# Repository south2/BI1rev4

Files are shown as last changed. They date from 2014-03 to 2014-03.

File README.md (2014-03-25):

BI1rev4
=======

BI1 revision 4 (myf14 evaluated, myf17 is work in progress)

The “body interactor”(BI) is a printed circuit board (PCB) with a vibrator motor, an accelerometer, a LiPo battery and battery charger and wireless radio frequency (RF) communication. The board can be programmed with the Arduino software.

The BI is designed for building a wearable autonomous device: With the accelerometer, movement data can be recorded and send to other BI by wireless RF communication. Gestures can be recognised and used for controlling the vibrator motor as well as other devices and applications using wireless communication (e.g. other BIs, computer games).

Different vibration pattern can be used to give the wearer information or feedback. Other use cases for vibration are massage application or moving objects (e.g. “vibrobot”).

The development board is particular suitable for people who are interested in application development using this kind of hardware arrangement and to construct an individual printed encasement for the board. Board, 3D printed encasement and Arduino program together are the individual final product. In addition the wireless communication function offers applications comprising multiple BI in different cases and with different tasks. In contrast changes, adaption or extensions (shields) of the board are rather complex.

www.bodyinteraction.com/about

Encasements

http://www.thingiverse.com/thing:109167

http://www.thingiverse.com/thing:259780

Data

- Atmel Attiny84 (8kbyte)
- LiPo charger (via USB)
- LiPo battery
- vibration motor (PWM controlled)
- BMA020 accelerometer
- two additional I/O ports  
- ISP interface (2×3 pole header) for programming
- RFM12B (915 or 868 Mhz)
- approx.  22×35 mm
- open source hardware

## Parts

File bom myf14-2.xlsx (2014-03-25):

 | BOM | 2014-03-12
 | Exported | from | myf14.brd
Quantity | Part | Value | Package (size in mm) | Orientation | Price (€) | Description (Package size in inch) | Ordered from | Order-ID | Manufacturer Part No | Remarks
2 | C4 | 1micro | 0603-CAP | R180 | 0.04 | Multilayer Ceramic Capacitors MLCC - SMD/SMT CAP, MLCC, 0201, 50V C0G 1pF 0.25pF tol | Mouser | 963-UMK063CG010CT-F | UMK063CG010CT-F |  | http://de.mouser.com/ProductDetail/Taiyo-Yuden/UMK063CG010CT-F/
3 | C7 | 0,1micro | 0603-CAP | R180 | 0.04 | Multilayer Ceramic Capacitors MLCC - SMD/SMT 0201 0.1pF 25volts C0G +/-0.1pF | Mouser | 81-GRM0335C1ER10BA1D | GRM0335C1ER10BA01D |  | http://de.mouser.com/ProductDetail/Murata/GRM0335C1ER10BA01D/
 | CHG | ORANGE | LED-0603 | R180 | 0.10 | Standard LEDs - SMD GaP Orange | Mouser | 630-HSMD-C190 | HSMD-C190 |  | http://de.mouser.com/ProductDetail/Avago-Technologies/HSMD-C190/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
 | MBR120ESF | CGRM4001-G | SOD-123_MINI-SMA | R90 | 0.20 | Schottky Diodes & Rectifiers 1A 20V | Mouser | 863-MBR120ESFT1G (https://de.mouser.com/Search/ProductDetail.aspx) | MBR120ESFT1G (https://de.mouser.com/Search/ProductDetail.aspx)
 | IC1 | Attiny84 | SOIC14 | R180 | 2.40 | 8-bit Microcontrollers - MCU 8-bit 512B SRAM 20MHz 2.7-5.5V | Mouser | 556-ATTINY84-20SSU | ATTINY84-20SSU |  | http://de.mouser.com/Search/ProductDetail.aspx
 | MGSF1N02LT1GOSCT-ND | BSS123 | SOT23 | R270 | 0.10 | MOSFET N-CH 20V 750MA SOT23 | digikey | MGSF1N02LT1GOSCT-ND | MGSF1N02LT1G (http://www.digikey.de/product-detail/en/MGSF1N02LT1G/MGSF1N02LT1GOSTR-ND/919442) |  | http://de.mouser.com/Search/ProductDetail.aspx
2 | R1 | 10K | R0603 | R90 | 0.02 | Thick Film Resistors - SMD 1/10watts 10Kohms 1% | Mouser | 660-RK73H1JTTD1002F | RK73H1JTTD1002F |  | https://de.mouser.com/Search/ProductDetail.aspx
 | R4 | 15 | R0603 | R0 | 0.02 | Thick Film Resistors - SMD 1/10watts 15ohms 1% | Mouser | 660-RK73H1JTTDD15R0F | RK73H1JTTDD15R0F |  | https://de.mouser.com/Search/ProductDetail.aspx
 | R6 | 50k | R0603 | R90 | 0.02 | Thick Film Resistors - SMD 1/10watts 49.9Kohms | Mouser | 660-RK73H1JTTD4992F | RK73H1JTTD4992F |  | https://de.mouser.com/Search/ProductDetail.aspx
 | R9 | 470 | R0603 | R180 | 0.01 | Thick Film Resistors - SMD 0603 470ohms 5% Tol | Mouser | 667-ERJ-3GEYJ471V | ERJ-3GEYJ471V |  | https://de.mouser.com/Search/ProductDetail.aspx
 | U2 | MAX1555 | SOT23-5 | R270 | 1.70 | Battery Management Dual USB/AC 1-Cell Li+ Battery Charger | Mouser | 700-MAX1555EZK+T | MAX1555EZK+T |  | http://de.mouser.com/Search/ProductDetail.aspx
 | X1 | USB-MICROB | USB-MICROB | R270 | 0.70 | USB Connectors MICRO B RECEPT RA SMT BTTM MNT | Mouser | 798-ZX62-B-5PA11 | ZX62-B-5PA(11) |  | https://de.mouser.com/Search/ProductDetail.aspx
 | U$1 | BMA020 | LBA-12 | R180 | 1.50 | BOSCH033 (BMA020) mobile phone chips gravity acceleration sensor | Aliexpress |  |  | ordered via aliexpress | http://www.aliexpress.com/snapshot/285585944.html
 | S1 | AYZ0202 | SparkFun-Electromechanical |  | 1.20 | SWITCH SLIDE SPDT 12V 100MA GW | digikey | 401-2012-1-ND | AYZ0102AGRLC (http://www.digikey.de/product-detail/en/AYZ0102AGRLC/401-2012-2-ND/1640108) |  | http://de.mouser.com/Search/ProductDetail.aspx
either 868 or 915 | RFM12B | RFM12B | RFM12B | MR270 | 4.50 | FM-RFM12B-868-S1 | octamex | FM-RFM12B-868-S1 | RFM12B-868-S1 | 868 MHz for Europe, select S1 or S2 type, both are ok
either 868 or 915 |  |  |  |  |  | RFM12B-S2 Wireless Transceiver - 915MHz | Sparcfun | WRL-12031 |  | 915 MHz for US and Australia, select S1 or S2 type, both are ok | https://www.sparkfun.com/products/12031
don't solder | SV1 | MA03-2-0.8 | JeeLabs |  | 0.29 | CONN HEADER 6POS .100 R/A 15AU | digikey | 609-3343-ND | 68021-206HLF
don't solder | U$2 | AVR-ISP-6-EDGE | 6PAD_ISP | R90 | 0.29 | CONN HEADER 6POS .100 STR 15AU | digikey | 609-3210-ND (http://www.digikey.com/product-detail/en/67996-206HLF/609-3210-ND/1878485) | 67996-206HLF (http://www.digikey.com/product-detail/en/67996-206HLF/609-3210-ND/1878485)
don't solder | JP2 | 100 mm wire for the antenna |  |  | ?
please solder | LiPo++ |  |  | akku | 2.00 | aliexpress | 150MAH 1S 20C MAX 40C 3.7V Toy helicopter LIPO PACK Nano Tech---RC01544 |  |  | or similair lipo with max size: XXX | http://www.aliexpress.com/snapshot/312605958.html
please solder | LiPo--
please solder | M++ |  |  | vibmotor | 6.00 |  | PicoVibe 7mm 1.V |  | 306-108
please solder | M--
marked in red = wrong identification on board and circuit layout - please ignore (only for reference)

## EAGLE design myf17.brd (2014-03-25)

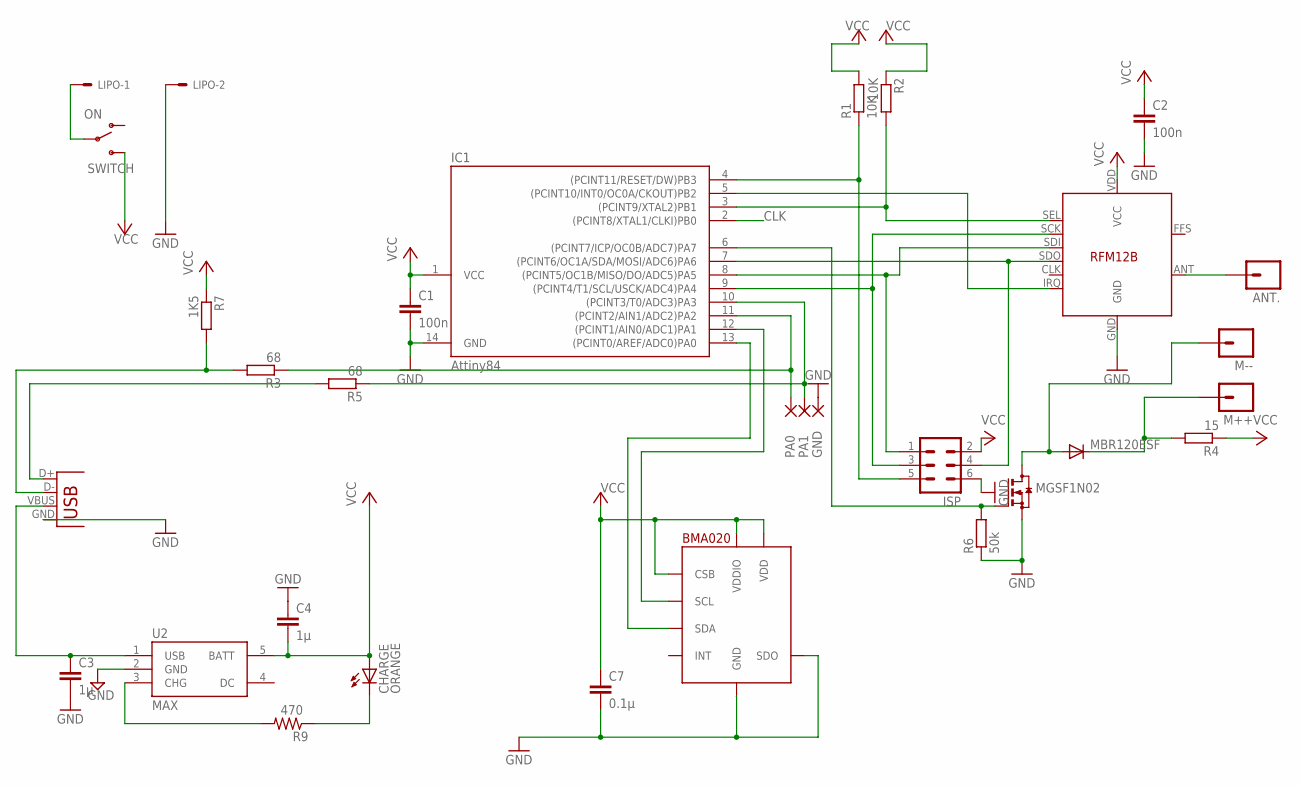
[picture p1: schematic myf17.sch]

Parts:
ANT.: M01PTH; 1X01
BMA020: BMA020; LBA-12
C1, C2: 100n; C0603K
C3, C4: 1µ; 0603-CAP
C7: 0.1µ; 0603-CAP
CHARGE: ORANGE; LED-0603
GND: SMD2; SMD1,27-2,54
IC1: Attiny84; SOIC14
ISP: MA03-2S; MA03-2-0.8
LIPO: SM02B-SRSS-TB
M++: M01PTH; 1X01
M--: M01PTH; 1X01
MBR120ESF: CGRM4001-G; SOD-123_MINI-SMA
MGSF1N02: BSS123; SOT23
PA0, PA1: SMD2; SMD1,27-2,54
R1, R2: 10K; R0603
R3, R5: 68; R0603
R4: 15; R0603
R6: 50k; R0603
R7: 1K5; R0603
R9: 470; R0603
RFM12B: RFM12B
SWITCH: ON; SWITCH-SPDT-SMD
U2: MAX; SOT23-5
USB: USB-MICROB

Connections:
CLK: IC1.2 ((PCINT8/XTAL1/CLKI)PB0)
GND: BMA020.P$3 (GND), BMA020.P$7 (SDO), C1.2, C2.2, C3.2, C4.1, C7.2, GND.1, IC1.14 (GND), ISP.6, LIPO.2, MGSF1N02.2 (S), R6.1, RFM12B.GND, U2.2 (GND), USB.GND
LED: BMA020.P$8 (SDA), IC1.13 ((PCINT0/AREF/ADC0)PA0)
unnamed: IC1.4 ((PCINT11/RESET/DW)PB3), ISP.5, R1.1
unnamed: IC1.3 ((PCINT9/XTAL2)PB1), R2.2, RFM12B.SEL
unnamed: ANT..1, RFM12B.ANT
unnamed: IC1.9 ((PCINT4/T1/SCL/USCK/ADC4)PA4), ISP.3, RFM12B.SCK
unnamed: IC1.8 ((PCINT5/OC1B/MISO/DO/ADC5)PA5), ISP.1, RFM12B.SDI
unnamed: IC1.7 ((PCINT6/OC1A/SDA/MOSI/ADC6)PA6), ISP.4, RFM12B.SDO
unnamed: IC1.5 ((PCINT10/INT0/OC0A/CKOUT)PB2), RFM12B.IRQ
unnamed: IC1.6 ((PCINT7/ICP/OC0B/ADC7)PA7), MGSF1N02.1 (G), R6.2
unnamed: IC1.10 ((PCINT3/T0/ADC3)PA3), PA1.1, R5.1
unnamed: IC1.11 ((PCINT2/AIN1/ADC2)PA2), PA0.1, R3.1
unnamed: BMA020.P$6 (SCL), IC1.12 ((PCINT1/AIN0/ADC1)PA1)
unnamed: M++.1, MBR120ESF.C, R4.2
unnamed: M--.1, MBR120ESF.A, MGSF1N02.3 (D)
unnamed: C3.1, U2.1 (USB), USB.VBUS
unnamed: LIPO.1, SWITCH.2
unnamed: R3.2, R7.2, USB.D-
unnamed: R5.2, USB.D+
unnamed: CHARGE.C, R9.1
unnamed: R9.2, U2.3 (CHG)
VCC: BMA020.P$2 (VDD), BMA020.P$5 (CSB), BMA020.P$9 (VDDIO), C1.1, C2.1, C4.2, C7.1, CHARGE.A, IC1.1 (VCC), ISP.2, R1.2, R2.1, R4.1, R7.1, RFM12B.VDD (VCC), SWITCH.3 (S), U2.5 (BATT)

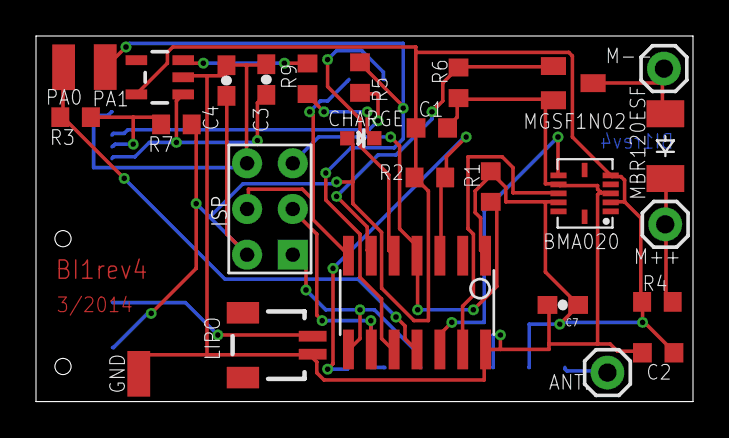
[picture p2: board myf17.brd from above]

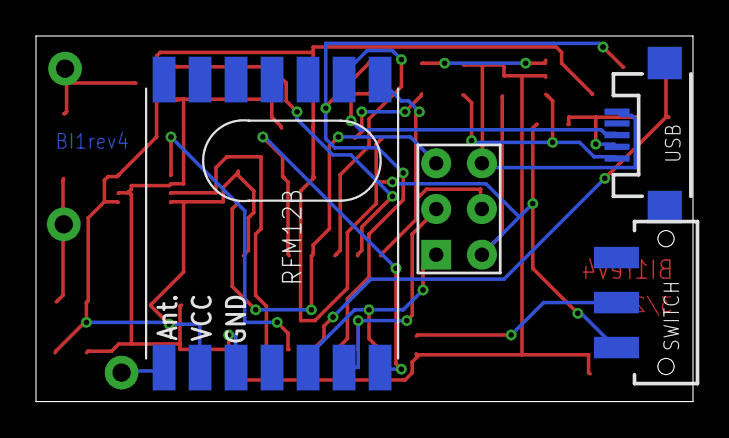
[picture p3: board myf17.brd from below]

Board: 4 copper layers, 36.5 x 20.3 mm, 30 parts (3 on the bottom side), 22 nets.

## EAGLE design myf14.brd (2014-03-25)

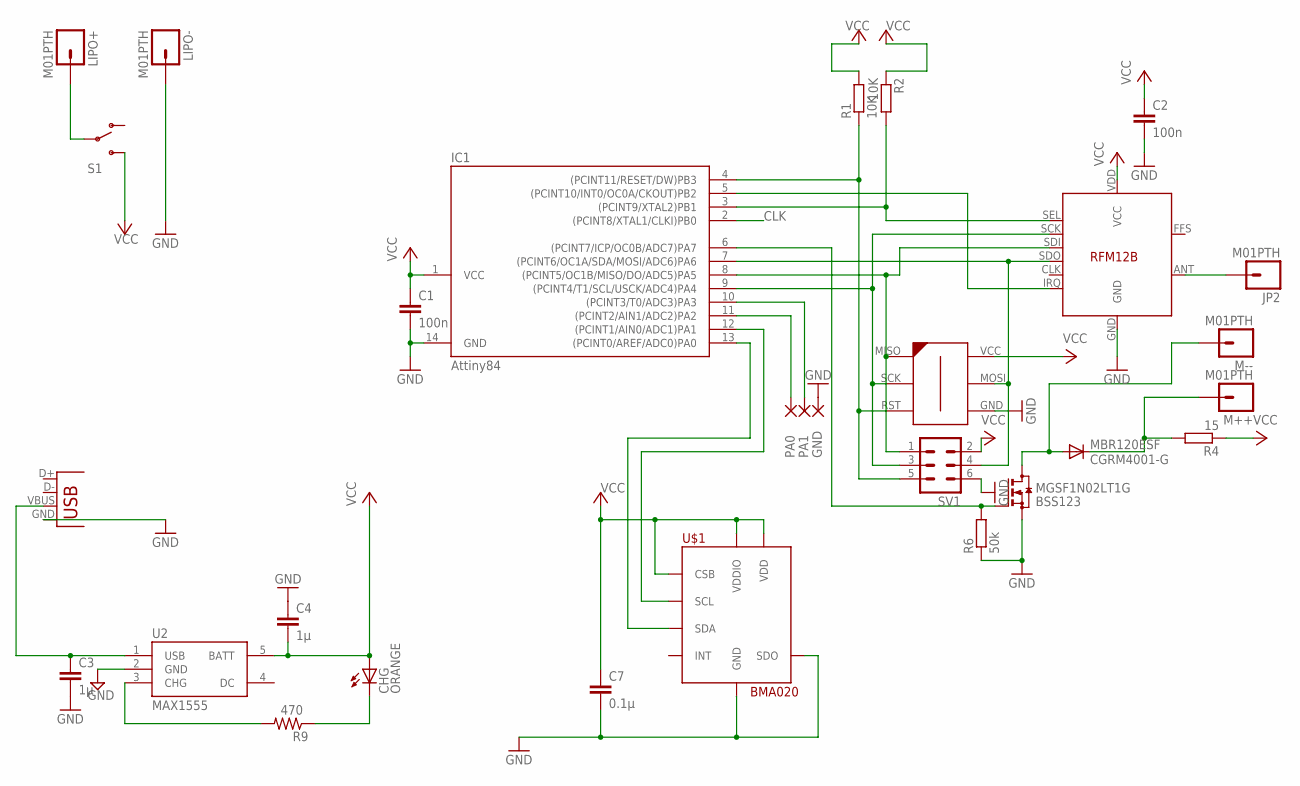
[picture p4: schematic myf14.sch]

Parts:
C1, C2: 100n; C0603K
C3, C4: 1µ; 0603-CAP
C7: 0.1µ; 0603-CAP
CHG: ORANGE; LED-0603
GND: SMD2; SMD1,27-2,54
IC1: Attiny84; SOIC14
JP2: M01PTH; 1X01
LIPO+: M01PTH; 1X01
LIPO-: M01PTH; 1X01
M++: M01PTH; 1X01
M--: M01PTH; 1X01
MBR120ESF: CGRM4001-G; SOD-123_MINI-SMA
MGSF1N02LT1G: BSS123; SOT23
PA0, PA1: SMD2; SMD1,27-2,54
R1, R2: 10K; R0603
R4: 15; R0603
R6: 50k; R0603
R9: 470; R0603
RFM12B: RFM12B
S1: SWITCH-SPDTSMD; AYZ0202
SV1: MA03-2S; MA03-2-0.8
U2: MAX1555; SOT23-5
U$1: BMA020; LBA-12
U$2: AVR-ISP-6-EDGE; 6PAD_ISP
X1: USB-MICROB

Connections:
CLK: IC1.2 ((PCINT8/XTAL1/CLKI)PB0)
GND: C1.2, C2.2, C3.2, C4.1, C7.2, GND.1, IC1.14 (GND), LIPO-.1, MGSF1N02LT1G.2 (S), R6.1, RFM12B.GND, SV1.6, U2.2 (GND), U$1.P$3 (GND), U$1.P$7 (SDO), U$2.GND, X1.GND
LED: IC1.13 ((PCINT0/AREF/ADC0)PA0), U$1.P$8 (SDA)
unnamed: IC1.4 ((PCINT11/RESET/DW)PB3), R1.1, SV1.5, U$2.RST
unnamed: IC1.3 ((PCINT9/XTAL2)PB1), R2.2, RFM12B.SEL
unnamed: JP2.1, RFM12B.ANT
unnamed: IC1.9 ((PCINT4/T1/SCL/USCK/ADC4)PA4), RFM12B.SCK, SV1.3, U$2.SCK
unnamed: IC1.8 ((PCINT5/OC1B/MISO/DO/ADC5)PA5), RFM12B.SDI, SV1.1, U$2.MISO
unnamed: IC1.7 ((PCINT6/OC1A/SDA/MOSI/ADC6)PA6), RFM12B.SDO, SV1.4, U$2.MOSI
unnamed: IC1.5 ((PCINT10/INT0/OC0A/CKOUT)PB2), RFM12B.IRQ
unnamed: IC1.6 ((PCINT7/ICP/OC0B/ADC7)PA7), MGSF1N02LT1G.1 (G), R6.2
unnamed: IC1.10 ((PCINT3/T0/ADC3)PA3), PA1.1
unnamed: IC1.11 ((PCINT2/AIN1/ADC2)PA2), PA0.1
unnamed: IC1.12 ((PCINT1/AIN0/ADC1)PA1), U$1.P$6 (SCL)
unnamed: M++.1, MBR120ESF.C, R4.2
unnamed: M--.1, MBR120ESF.A, MGSF1N02LT1G.3 (D)
unnamed: C3.1, U2.1 (USB), X1.VBUS
unnamed: LIPO+.1, S1.2
unnamed: CHG.C, R9.1
unnamed: R9.2, U2.3 (CHG)
VCC: C1.1, C2.1, C4.2, C7.1, CHG.A, IC1.1 (VCC), R1.2, R2.1, R4.1, RFM12B.VDD (VCC), S1.3 (S), SV1.2, U2.5 (BATT), U$1.P$2 (VDD), U$1.P$5 (CSB), U$1.P$9 (VDDIO), U$2.VCC

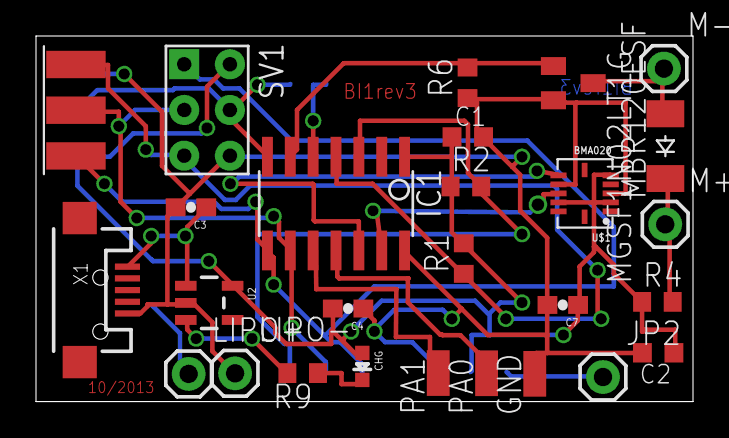
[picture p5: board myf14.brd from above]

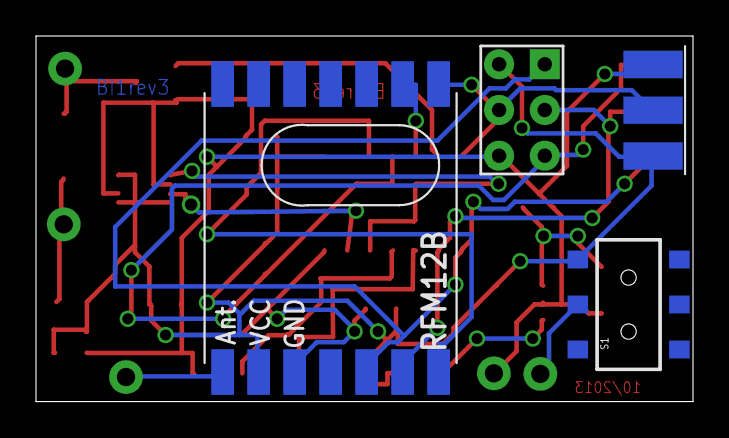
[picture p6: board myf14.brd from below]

Board: 4 copper layers, 36.5 x 20.3 mm, 29 parts (2 on the bottom side), 20 nets.

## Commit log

2014-03-25 BI1 circuit layout
    [bom myf14-2.xlsx, myf14.brd, myf14.sch]
2014-03-25 layout with V-USB
    [myf17.brd, myf17.sch]

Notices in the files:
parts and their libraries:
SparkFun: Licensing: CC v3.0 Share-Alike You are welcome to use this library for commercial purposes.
